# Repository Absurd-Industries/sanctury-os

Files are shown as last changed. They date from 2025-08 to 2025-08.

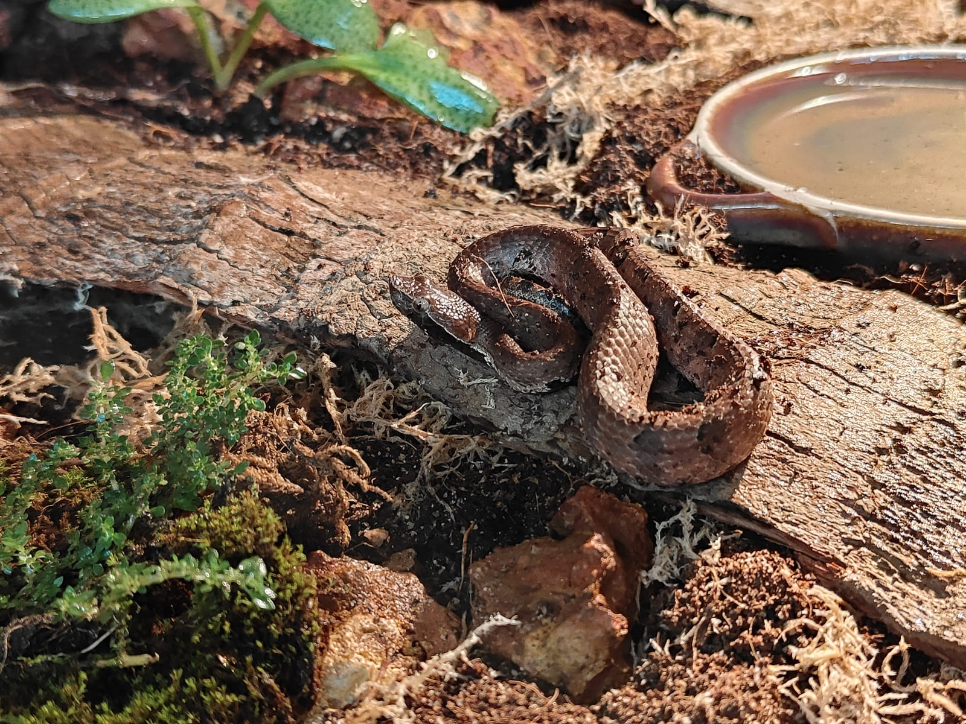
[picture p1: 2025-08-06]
images/HyHyKa01.jpg

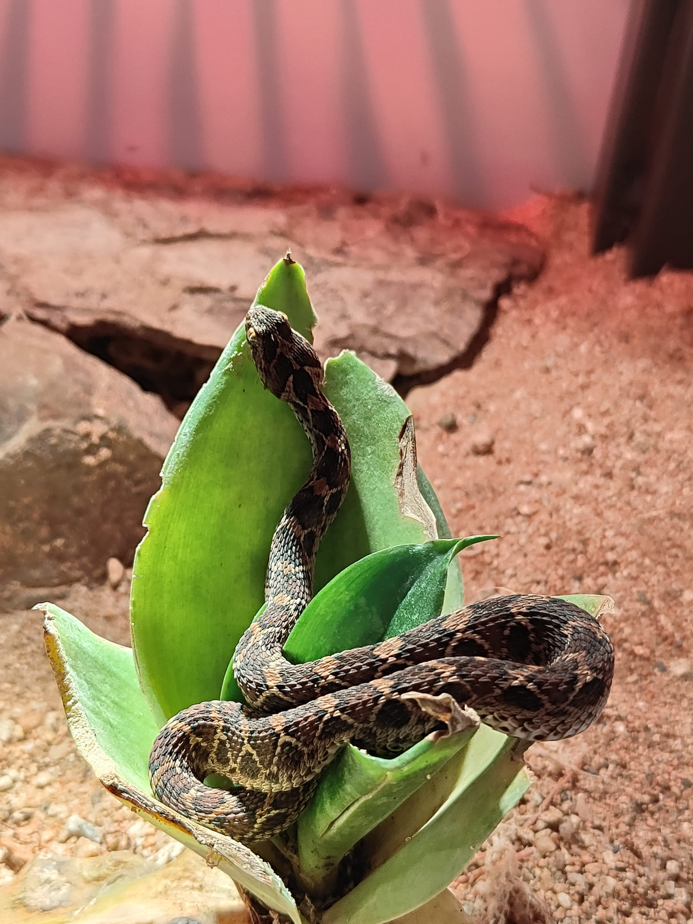
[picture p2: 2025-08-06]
images/EcCaKa01.jpg

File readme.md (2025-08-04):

# Sanctuary OS
## Real-Time Wildlife Conservation Monitoring Platform

  

**Sanctuary OS** is a comprehensive environmental monitoring and management system designed specifically for wildlife conservation facilities. Built by [Absurd Industries](https://absurd.industries) in collaboration with [The Liana Trust](https://www.thelianatrust.org/), UI design by [Code Uncode](https://codeuncode.com) this platform transforms traditional habitat monitoring into an intelligent, real-time conservation tool.

---

## 🐍 **The Problem We're Solving**

Wildlife conservation facilities face critical challenges in maintaining optimal environmental conditions for their residents:

- **Manual monitoring** is time-intensive and prone to human error
- **Environmental fluctuations** can be life-threatening for ectothermic species
- **Data collection** is often fragmented across multiple systems
- **Emergency response** requires immediate awareness of critical changes
- **Research documentation** needs consistent, accurate environmental data

Traditional monitoring methods simply can't provide the granular, real-time data required for modern conservation science.

---

## 🎯 **Our Solution**

Sanctuary OS provides a **unified, intelligent monitoring platform** that combines:

### **Real-Time Environmental Monitoring**
- **Temperature** tracking with ±0.1°C precision
- **Humidity** monitoring with ±2% accuracy  
- **UV Index** measurement for ectothermic health requirements
- **Multi-sensor networks** for comprehensive habitat coverage

### **Intelligent Interface Design**
- **Mobile-first responsive design** for field use
- **Live camera integration** for visual monitoring
- **Glass-morphism overlays** for at-a-glance data visualization
- **Admin-friendly editing** for rapid data updates

### **Conservation-Focused Features**
- **Species-specific optimal ranges** with visual indicators
- **Care schedule tracking** and reminder systems
- **Research note management** for scientific documentation
- **Export capabilities** for academic collaboration

---

## 🔧 **Technical Architecture**

### **Frontend Stack**
- **Vue.js 3** - Reactive framework for dynamic interfaces
- **Tailwind CSS** - Utility-first styling with custom conservation color palette
- **FontAwesome** - Comprehensive iconography
- **Responsive Design** - Mobile-first approach for field accessibility

### **Sensor Integration**
- **Modular sensor networks** supporting 2-10 collection points per enclosure
- **Real-time data streaming** with configurable update frequencies
- **Fail-safe monitoring** with offline data retention
- **Scalable architecture** for facility expansion

### **Data Management**
- **Real-time updates** every 5-60 seconds (configurable)
- **Historical data tracking** for trend analysis
- **CSV export functionality** for research collaboration
- **Backup and redundancy** systems

---

## 📊 **Deployment Configurations**

### **Standard Enclosures**
- **2 sensor collection points** per habitat
- Basic environmental monitoring
- Suitable for: Educational animals, non-critical species

### **Large Enclosures** 
- **10 sensor collection points** per habitat
- Comprehensive environmental mapping
- Suitable for: Venomous species, breeding programs, research subjects

### **Outdoor Habitats**
- **Weather-resistant sensor packages**
- Extended battery life systems
- Solar charging capability
- Suitable for: Semi-natural enclosures, rehabilitation areas

---

## 🛠 **Hardware Requirements (WIP)**

### **Sensor Package (Per Collection Point)**
- **Temperature Sensor**: DHT22 or SHT30 (±0.1°C accuracy)
- **Humidity Sensor**: Integrated with temperature module
- **UV Sensor**: SI1145 or VEML6070 (UV Index measurement)
- **Microcontroller**: ESP32 (WiFi + Bluetooth capability)
- **Power Management**: 5V wired input
- **Enclosure**: IP65-rated weatherproof housing

### **Network Infrastructure**
- **WiFi Access Points** for sensor connectivity
- **Central Hub**: Raspberry Pi 4 or equivalent
- **Backup Storage**: Local SD card + cloud synchronization
- **Display Hardware**: Tablets/monitors for kiosk mode

### **Optional Equipment**
- **Camera Modules**: ESP32-CAM for live feeds
- **Solar Panels**: For outdoor/remote installations
- **LoRa Modules**: For long-range, low-power communication
- **Alarm Systems**: Audio/visual alerts for critical conditions

---

## 📋 **Bill of Materials (BOM) - Placeholder**

*Please provide the following information to generate accurate costings:*

### **Facility Requirements**
- [ ] Total number of enclosures requiring monitoring
- [ ] Number of standard vs. large monitoring setups needed
- [ ] Outdoor enclosure requirements
- [ ] Existing WiFi infrastructure capabilities
- [ ] Power availability at sensor locations

### **Species-Specific Data**
- [ ] Complete list of resident species
- [ ] Optimal temperature ranges for each species
- [ ] Optimal humidity ranges for each species  
- [ ] UV requirements (diurnal vs. nocturnal species)
- [ ] Critical alert thresholds
- [ ] Feeding schedules and care protocols

### **Technical Preferences**
- [ ] Preferred sensor update frequency
- [ ] Data retention requirements
- [ ] Integration with existing systems
- [ ] User access levels and permissions
- [ ] Backup and redundancy preferences

---

## 💡 **Key Benefits**

### **For Conservation**
- **Improved animal welfare** through precise environmental control
- **Enhanced research capabilities** with consistent data collection
- **Reduced monitoring workload** through automation
- **Emergency response** via real-time alerts

### **For Operations**
- **Cost reduction** through efficient resource management
- **Staff productivity** gains from streamlined workflows
- **Visitor education** through transparent monitoring displays
- **Grant applications** strengthened by comprehensive data

### **For Research**
- **High-resolution environmental data** for scientific studies
- **Behavioral correlation** with environmental conditions
- **Breeding program optimization** through precise habitat control
- **Conservation protocol development** based on empirical evidence

---

## 📱 **Live Demo**

Experience Sanctuary OS in action: [**sanctuary.absurd.industries**](https://sanctuary.absurd.industries)

---

## 🤝 **Partnership & Support**

### **Absurd Industries**
Open-source hardware guild committed to building repairable, accessible technology for conservation.

**Contact:** [amit@absurd.industries](mailto:amit@absurd.industries)  
**Web:** [absurd.industries](https://absurd.industries)

---

## 🌱 **Open Source Commitment**

Sanctuary OS is built on open-source principles:

- **Hardware designs** available under Creative Commons
- **Software code** licensed under GPL v3
- **Documentation** freely accessible
- **Community contributions** welcomed and supported

---

*Built with ❤️ by for the global conservation community. Because conservation technology should be accessible to everyone working to protect our planet's biodiversity.*

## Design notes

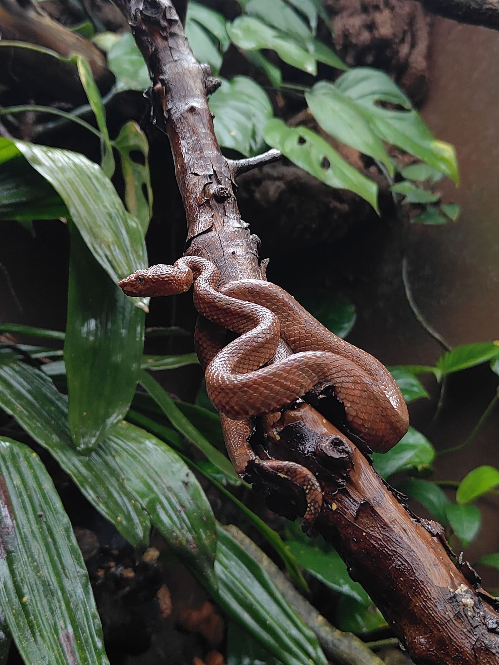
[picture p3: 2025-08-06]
images/CrMlKa03.jpg

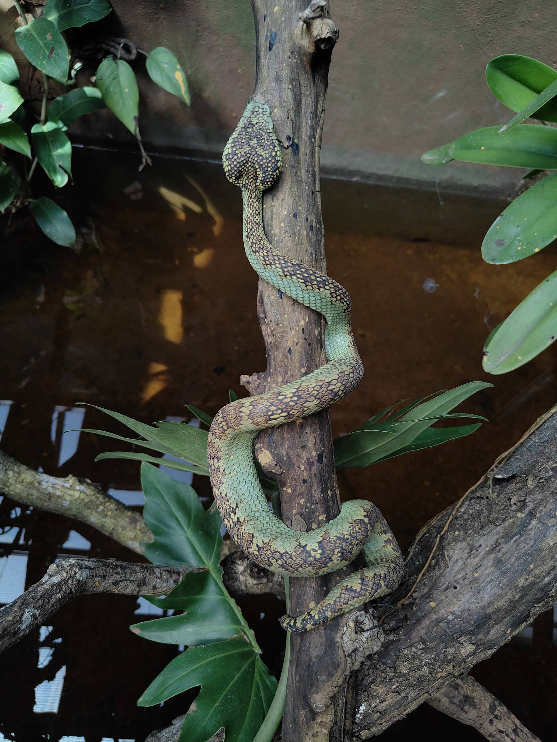
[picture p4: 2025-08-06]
images/CrMlKa02.jpg

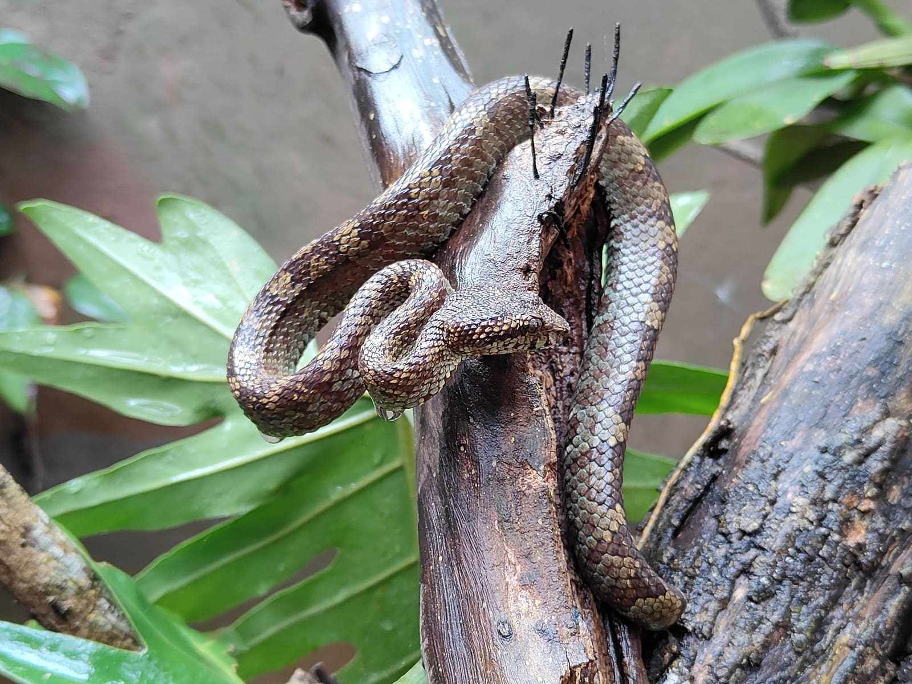
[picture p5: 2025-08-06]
images/CrMlKa01.jpg

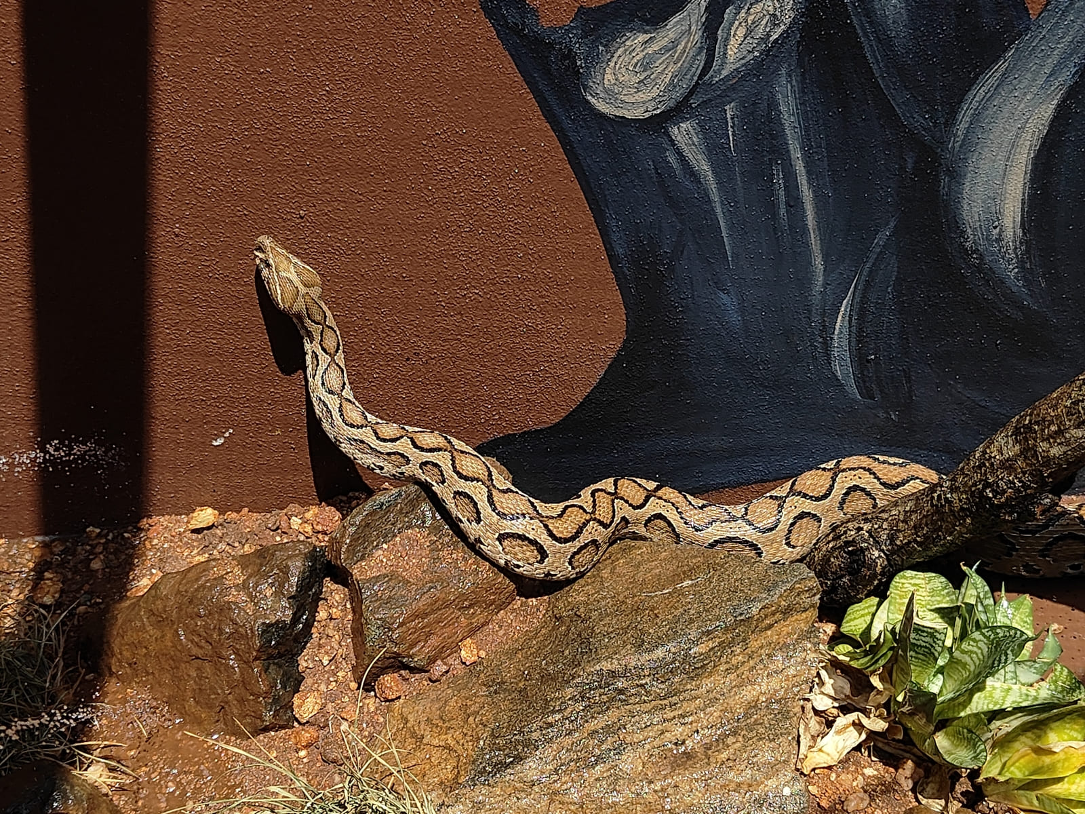
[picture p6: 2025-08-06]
images/DaRuKa05.jpg

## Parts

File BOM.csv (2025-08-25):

Component | Category | Quantity | Unit_Price_INR | Total_Price_INR | Supplier | Supplier_Location | Delivery_Time | Link | Notes
ESP32 Development Board (38-pin) | Core Electronics | 3 | 449 | 1347 | Robocraze | Kalyan Nagar Bengaluru | Same Day | https://robocraze.com/products/esp32-development-board | WiFi + Bluetooth dual-core
BME280 Environmental Sensor | Core Electronics | 3 | 299 | 897 | Robocraze | Kalyan Nagar Bengaluru | Same Day | https://robocraze.com/products/bme280-temperature-sensor-module | ±0.5°C accuracy temp/humidity/pressure
BH1750 Light Sensor | Core Electronics | 3 | 129 | 387 | Robocraze | Kalyan Nagar Bengaluru | Same Day | https://robocraze.com/products/bh1750-light-sensor | 16-bit resolution 1-65535 lux
HC-SR501 PIR Motion Sensor | Core Electronics | 3 | 79 | 237 | Robocraze | Kalyan Nagar Bengaluru | Same Day | https://robocraze.com/products/hcsr501-pir-motion-sensor-passive-infrared-sensor | Passive infrared 3-7m range
ESP32-CAM with OV2640 | Camera System | 3 | 210 | 630 | Robocraze | Kalyan Nagar Bengaluru | Same Day | https://robocraze.com/products/esp32-camera-module | 2MP camera with WiFi streaming
Samsung 18650 2600mAh Battery | Power System | 3 | 317 | 951 | Robu.in | Pan-India | 2-3 Days | https://robu.in/product/samsung-icr18650-26-jm-2600mah-li-ion-battery/ | High-drain lithium-ion cell
TP4056 USB-C Charging Module | Power System | 3 | 169 | 507 | Robu.in | Pan-India | 2-3 Days | https://robu.in/product/tp4056-1a-li-ion-lithium-battery-charging-module-with-current-protection-type-c/ | 1A charging with protection
18650 Battery Holder (SMD) | Power System | 3 | 95 | 285 | Robu.in | Pan-India | 2-3 Days | https://robu.in/product/18650-battery-holder-smd-smt/ | Surface mount design
3.3V Buck/Boost Converter | Power System | 3 | 51 | 153 | Robu.in | Pan-India | 2-3 Days | https://robu.in/product/dc-dc-1-8v-5v-to-3-3v-boost-and-buck-power-module/ | Voltage regulation 1.8V-5V input
JST XH Connectors (Mixed Pack) | Assembly Hardware | 10 | 18 | 180 | Robu.in | Pan-India | 2-3 Days | https://robu.in/product/4-pin-jst-xh-2-54mm-pitch-plug-and-socket-with-cable-5-pcs/ | 2/3/4-pin with cables
Conformal Coating (250ml) | Protection | 1 | 450 | 450 | Robu.in | Pan-India | 2-3 Days | https://robu.in/product/conformal-coating/ | Acrylic PCB protection
Cable Glands & Assembly Parts | Assembly Hardware | 1 | 300 | 300 | Robu.in | Pan-India | 2-3 Days | https://robu.in/ | Mixed components bulk order
IP65 Waterproof Enclosure | Housing | 3 | 400 | 1200 | Amazon India | Bengaluru | 1-2 Days | https://www.amazon.in/s?k=IP65+waterproof+enclosure | 80x120x85mm ABS plastic
PG7 Cable Glands | Housing | 6 | 35 | 210 | GM Modular | Jayanagar Bengaluru | Same Day | https://gmmodular.com/store-locator | Waterproof cable entry
Assembly Materials | Assembly Hardware | 1 | 420 | 420 | Local Suppliers | Bengaluru | Same Day | Various | Wires sealant hardware
10k Resistor Pack | Electronic Components | 1 | 25 | 25 | Robocraze | Kalyan Nagar Bengaluru | Same Day | https://robocraze.com/ | Pull-up resistors for I2C
4.7k Resistor Pack | Electronic Components | 1 | 25 | 25 | Robocraze | Kalyan Nagar Bengaluru | Same Day | https://robocraze.com/ | Standard I2C pull-ups
Status LEDs (Red/Green/Blue) | Electronic Components | 15 | 3 | 45 | Robocraze | Kalyan Nagar Bengaluru | Same Day | https://robocraze.com/ | Power and status indicators
Silicone Wire (22AWG) | Assembly Hardware | 10 | 15 | 150 | Robocraze | Kalyan Nagar Bengaluru | Same Day | https://robocraze.com/ | Flexible high-temp wire
Heat Shrink Tubing Kit | Assembly Hardware | 1 | 80 | 80 | Robocraze | Kalyan Nagar Bengaluru | Same Day | https://robocraze.com/ | Various sizes assortment
Dupont Jumper Wires | Assembly Hardware | 1 | 120 | 120 | Robocraze | Kalyan Nagar Bengaluru | Same Day | https://robocraze.com/ | 120-piece male/female set
M3 Mounting Hardware Kit | Assembly Hardware | 1 | 85 | 85 | Robocraze | Kalyan Nagar Bengaluru | Same Day | https://robocraze.com/ | Screws nuts washers
PCB Standoffs (M3) | Assembly Hardware | 20 | 8 | 160 | Robu.in | Pan-India | 2-3 Days | https://robu.in/ | Component mounting spacers
Aquarium-Safe Silicone Sealant | Protection | 2 | 120 | 240 | Local Hardware Store | Bengaluru | Same Day | Local | Non-toxic weatherproofing
Acrylic Sheet (Clear 2mm) | Housing | 1 | 200 | 200 | Local Plastics Supplier | Bengaluru | Same Day | Local | Light sensor windows
Antenna Extension Cable (SMA) | Connectivity | 3 | 45 | 135 | Robu.in | Pan-India | 2-3 Days | https://robu.in/ | External WiFi antenna option

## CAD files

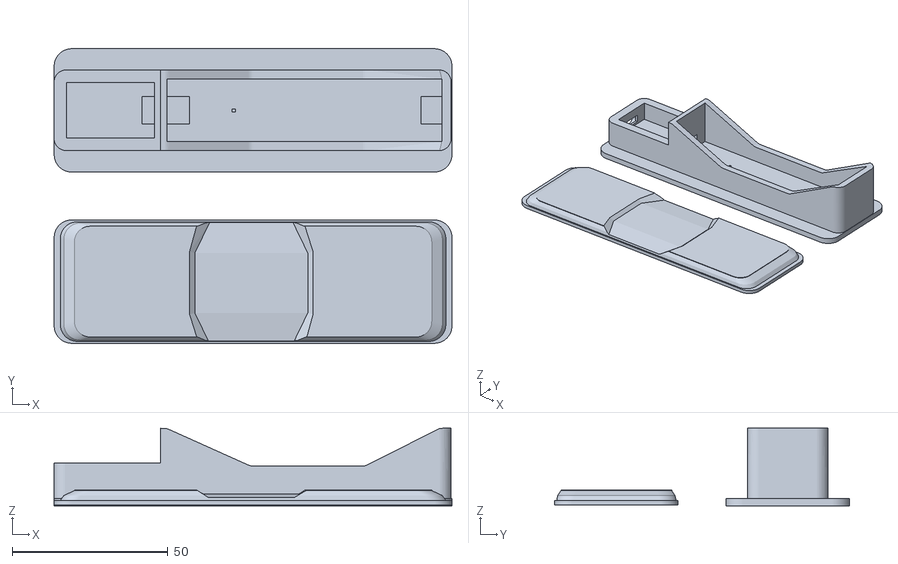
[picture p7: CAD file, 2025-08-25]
3d-models/INSIDE BOTH LAYERS.stl
127.9 x 94.7 x 24.9

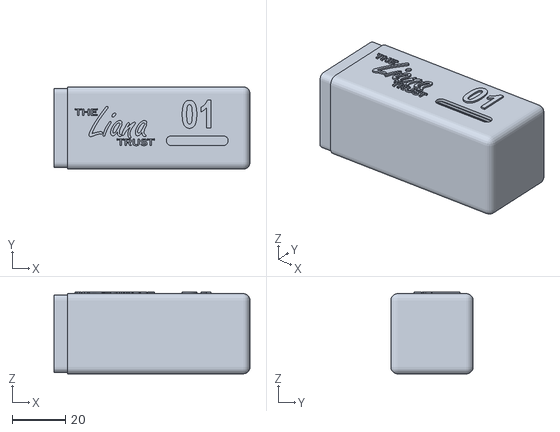
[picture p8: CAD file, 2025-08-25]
3d-models/print/CASE BODY.stl
73.8 x 30.9 x 30.8

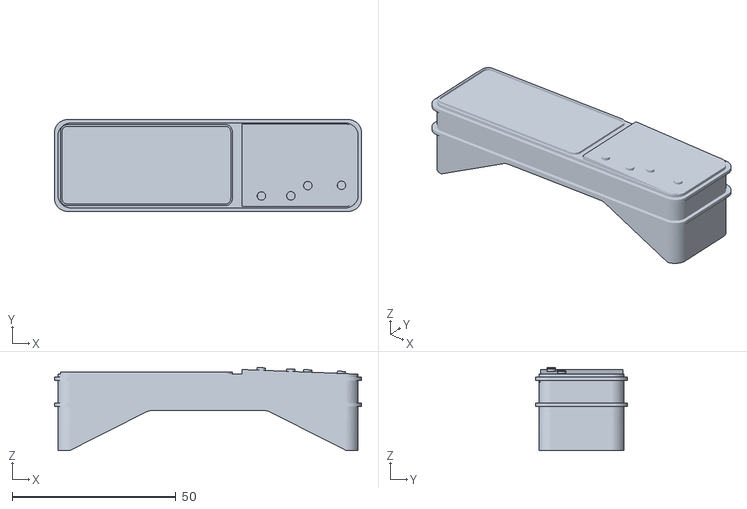
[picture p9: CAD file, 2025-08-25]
3d-models/iner pod v2.stl
93.7 x 28.1 x 25.4

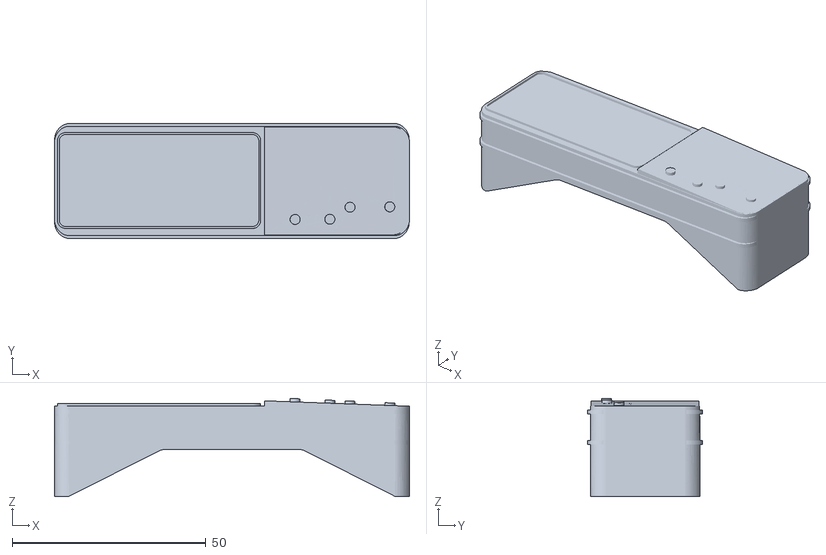
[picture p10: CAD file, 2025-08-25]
3d-models/print/sensor-pod-body.stl
91.6 x 29.7 x 25.4

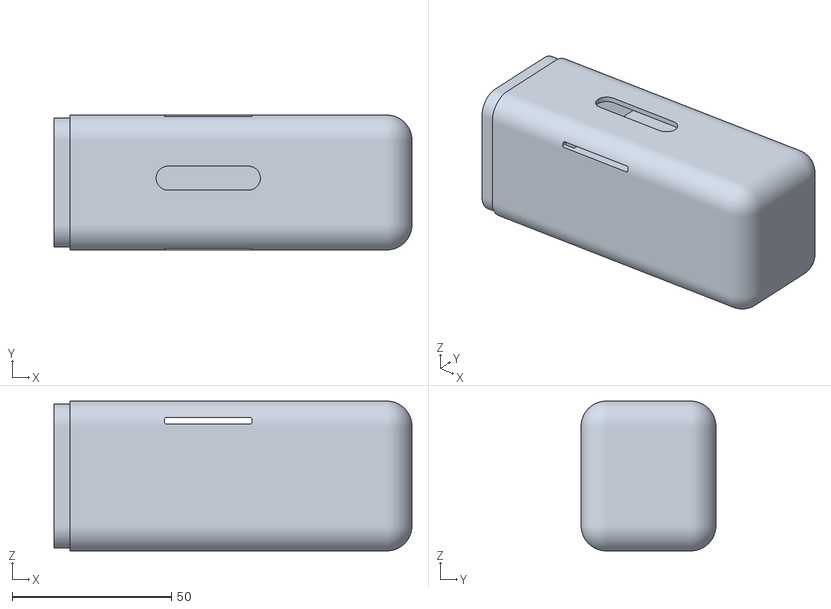
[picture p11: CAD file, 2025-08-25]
3d-models/case.stl
112.3 x 42.3 x 47.0

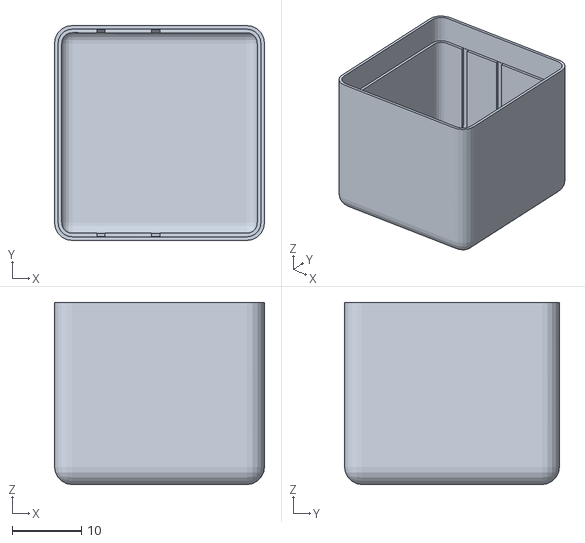
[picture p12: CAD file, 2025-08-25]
3d-models/print/CASE LID.stl
30.2 x 30.9 x 26.2

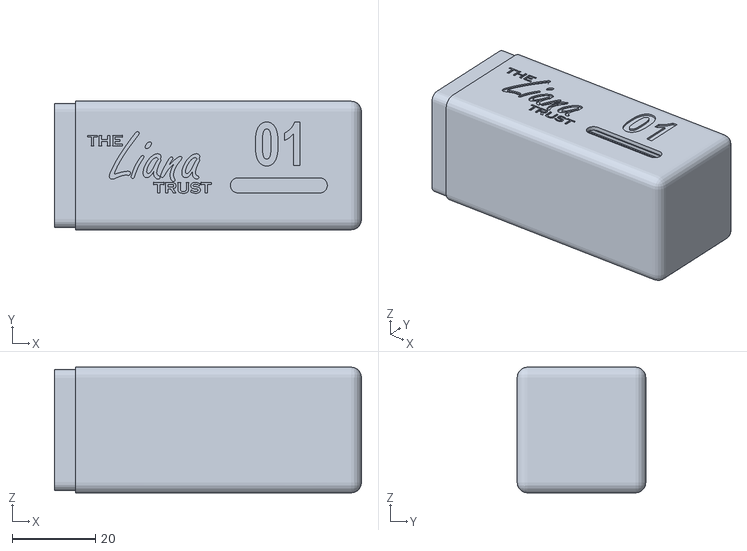
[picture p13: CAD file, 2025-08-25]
3d-models/print/BODY CASE WITH LOGO.stl
73.8 x 30.9 x 30.2

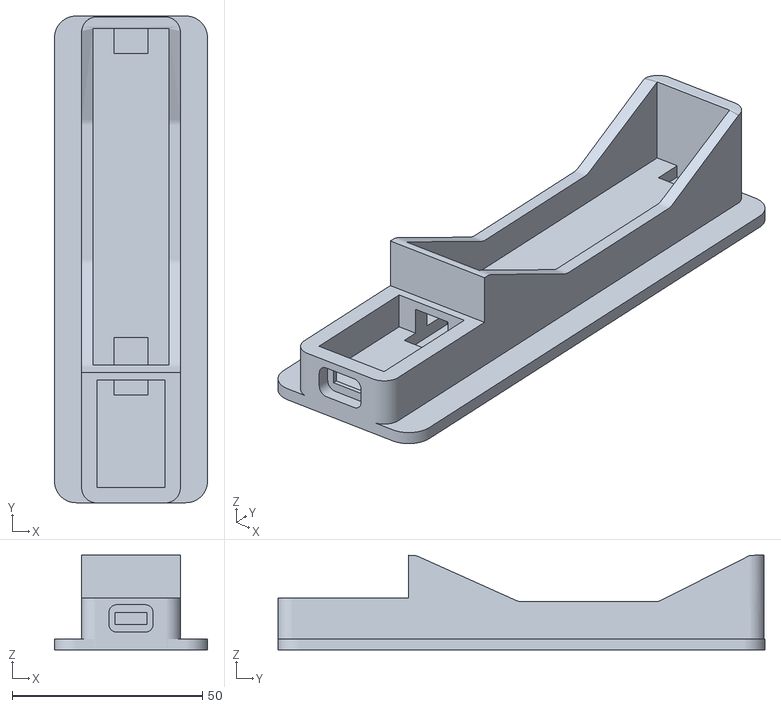
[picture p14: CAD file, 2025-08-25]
3d-models/18650-tp4056-holder-test.stl
40.2 x 127.9 x 24.8

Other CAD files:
3d-models/sensor-pod-body.blend
3d-models/sensor-pod-body.obj

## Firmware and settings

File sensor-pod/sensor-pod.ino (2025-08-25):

/**
 * Wildlife Conservation Monitoring System - The Liana Trust
 * "Actually Works This Time" Edition 🐍
 * 
 * Hardware: PCB Cupid Glyph C3 (ESP32-C3)
 * Sensors: BH1750 Light Sensor, BME280 Environmental Sensor
 * Purpose: Snake habitat monitoring that Lisa will absolutely LOVE
 * 
 * Authors: Amartha (Maximum Sass Division) & Amit (The Snake Whisperer)
 * Version: 2.0.0 - "Complete and Fabulous Edition"
 * Date: When snakes learn to code (approximately now)
 */

// ===== LIBRARY IMPORTS =====
#include <WiFi.h>
#include <PubSubClient.h>
#include <ArduinoJson.h>
#include <Wire.h>
#include <BH1750.h>
#include <BME280I2C.h>  // Tyler Green's library - because it actually works
#include "esp_task_wdt.h"
#include "esp_sleep.h"
#include <time.h>
#include <ESPmDNS.h>

// ===== HARDWARE CONFIGURATION =====
// I2C Pin Configuration for PCB Cupid Glyph C3
#define I2C_SDA 4          // GPIO4 - I2C Data Line
#define I2C_SCL 5          // GPIO5 - I2C Clock Line
#define CS_PIN 0           // GPIO0 - Chip Select on D0
#define LED_PIN 2          // Built-in LED for status indication

// Sensor I2C Addresses
#define BH1750_ADDR 0x23   // Light sensor address (ADD pin LOW/floating)
#define BME280_ADDR 0x76   // Environmental sensor default address

// ===== NETWORK CONFIGURATION =====
const char* WIFI_SSID = "@manjusstudio";
const char* WIFI_PASSWORD = "wifi2020!";

// MQTT Configuration with intelligent fallback system
const char* MQTT_BROKER_HOSTNAME = "liana.local";       // Primary target
const char* MQTT_BROKER_IP = "192.168.1.100";          // UPDATE THIS IP!
const char* MQTT_TEST_BROKER = "test.mosquitto.org";   // Public test broker
const int MQTT_PORT = 1883;
const char* MQTT_CLIENT_ID = "sanctuary_glyph_c3_001";
const char* MQTT_USER = "";      // Add if your broker requires auth
const char* MQTT_PASSWORD = "";  // Add if your broker requires auth

// MQTT Topics - Wildlife Conservation Standard
const char* TOPIC_SENSOR_DATA = "liana/habitat/sensors";
const char* TOPIC_ALERTS = "liana/habitat/alerts";
const char* TOPIC_STATUS = "liana/habitat/status";
const char* TOPIC_COMMANDS = "liana/habitat/commands";
const char* TOPIC_DIAGNOSTICS = "liana/habitat/diagnostics";

// ===== TIMING CONFIGURATION (in seconds) =====
const unsigned long SENSOR_READ_INTERVAL = 30;      // Read sensors every 30 seconds
const unsigned long MQTT_PUBLISH_INTERVAL = 60;     // Publish every minute for demo
const unsigned long WIFI_CHECK_INTERVAL = 30;       // Check WiFi every 30 seconds
const unsigned long HEARTBEAT_INTERVAL = 300;       // Heartbeat every 5 minutes
const uint32_t WDT_TIMEOUT = 30;                     // Watchdog timeout

// ===== WILDLIFE MONITORING THRESHOLDS =====
// Temperature thresholds for snake habitats (Celsius)
const float TEMP_CRITICAL_LOW = 15.0;    // Critical low temperature
const float TEMP_CRITICAL_HIGH = 40.0;   // Critical high temperature
const float TEMP_WARNING_LOW = 18.0;     // Warning low temperature
const float TEMP_WARNING_HIGH = 35.0;    // Warning high temperature
const float TEMP_OPTIMAL_MIN = 22.0;     // Optimal range minimum
const float TEMP_OPTIMAL_MAX = 30.0;     // Optimal range maximum

// Humidity thresholds (%)
const float HUMIDITY_CRITICAL_LOW = 20.0;
const float HUMIDITY_CRITICAL_HIGH = 95.0;
const float HUMIDITY_WARNING_LOW = 30.0;
const float HUMIDITY_WARNING_HIGH = 85.0;
const float HUMIDITY_OPTIMAL_MIN = 45.0;
const float HUMIDITY_OPTIMAL_MAX = 75.0;

// Light thresholds (lux) for day/night cycle detection
const float LUX_DAY_THRESHOLD = 100.0;
const float LUX_NIGHT_THRESHOLD = 10.0;
const float LUX_TWILIGHT_THRESHOLD = 50.0;

// ===== GLOBAL OBJECTS =====
BH1750 lightMeter;
BME280I2C bme;    // Tyler Green's BME280 library - the hero we deserved
WiFiClient wifiClient;
PubSubClient mqttClient(wifiClient);

// Connection state tracking
String currentMqttBroker = "";
int currentMqttPort = 0;
bool usingTestBroker = false;

// ===== DATA STRUCTURES =====
struct SensorReading {
  unsigned long timestamp;
  float temperature;
  float humidity;
  float pressure;
  float light_lux;
  int wifi_rssi;
  String light_condition;  // "day", "night", "twilight"
  bool temp_critical;
  bool temp_warning;
  bool humidity_critical;
  bool humidity_warning;
  bool all_optimal;
};

struct AlertLevel {
  String severity;  // "critical", "warning", "info"
  String type;      // "temperature", "humidity", "light", "system"
  String message;
  unsigned long timestamp;
};

// Data buffer for offline storage (because network outages happen)
#define BUFFER_SIZE 100
SensorReading dataBuffer[BUFFER_SIZE];
int bufferIndex = 0;
int bufferCount = 0;

// Alert tracking
AlertLevel lastAlert;
bool alertActive = false;
unsigned long lastAlertTime = 0;

// ===== TIMING VARIABLES =====
unsigned long lastSensorRead = 0;
unsigned long lastMqttPublish = 0;
unsigned long lastWifiCheck = 0;
unsigned long lastHeartbeat = 0;
unsigned long bootTime = 0;
unsigned long totalUptime = 0;
int reconnectAttempts = 0;
int totalMqttPublishes = 0;
int totalAlerts = 0;

// ===== STATUS FLAGS =====
bool sensorsInitialized = false;
bool bmeWorking = false;
bool lightSensorWorking = false;
bool wifiConnected = false;
bool mqttConnected = false;
bool systemHealthy = true;

// ===== FUNCTION DECLARATIONS =====
void initializeSensors();
void connectWiFi();
void connectMQTT();
void reconnectMQTT();
void checkConnections();
SensorReading readSensors();
void publishSensorData(SensorReading& reading);
void publishAlert(AlertLevel alert);
void checkEnvironmentalAlerts(SensorReading& reading);
void storeReading(SensorReading& reading);
void publishBufferedData();
void publishHeartbeat();
void mqttCallback(char* topic, byte* payload, unsigned int length);
void handleCommand(String command, String value);
bool isI2CDevicePresent(uint8_t address);
void printDiagnostics();
void blinkLED(int times, int delayMs = 200);
String getSystemStatus();
String getLightCondition(float lux);
void enterDeepSleep(uint64_t seconds);

// ===== SETUP FUNCTION =====
void setup() {
  // Initialize serial communication for debugging
  Serial.begin(115200);
  delay(1000);
  
  Serial.println("\n" + String("="));
  Serial.println("WILDLIFE CONSERVATION MONITORING SYSTEM");
  Serial.println("Device: PCB Cupid Glyph C3 (ESP32-C3)");
  Serial.println("Purpose: The Liana Trust Snake Habitat Monitoring");
  Serial.println(String("=") + "\n");
  
  // Initialize hardware pins
  pinMode(CS_PIN, OUTPUT);
  digitalWrite(CS_PIN, HIGH);  // Deselect by default
  pinMode(LED_PIN, OUTPUT);
  
  // Boot indication - because feedback is important
  blinkLED(3, 100);
  
  // Initialize watchdog timer for ESP32-C3 (because things can go wrong)
  esp_task_wdt_config_t wdt_config = {
    .timeout_ms = WDT_TIMEOUT * 1000,
    .idle_core_mask = (1 << portNUM_PROCESSORS) - 1,
    .trigger_panic = true
  };
  esp_task_wdt_init(&wdt_config);
  esp_task_wdt_add(NULL);
  Serial.println("✓ Watchdog timer initialized (30s timeout)");
  
  // Initialize I2C bus with proper error handling
  Wire.begin(I2C_SDA, I2C_SCL);
  Wire.setClock(100000);  // 100kHz for maximum reliability
  Serial.println("✓ I2C bus initialized on SDA=GPIO4, SCL=GPIO5");
  
  // Comprehensive I2C device scan
  Serial.println("\n🔍 Scanning I2C bus for devices...");
  bool devicesFound = false;
  for (byte address = 1; address < 127; address++) {
    Wire.beginTransmission(address);
    if (Wire.endTransmission() == 0) {
      Serial.print("  📍 I2C device found at 0x");
      if (address < 16) Serial.print("0");
      Serial.print(address, HEX);
      
      // Identify known devices
      switch(address) {
        case 0x23: Serial.println(" (BH1750 Light Sensor)"); break;
        case 0x76: Serial.println(" (BME280 Environmental Sensor)"); break;
        case 0x77: Serial.println(" (BME280 Alt Address)"); break;
        default: Serial.println(" (Unknown Device)"); break;
      }
      devicesFound = true;
    }
  }
  
  if (!devicesFound) {
    Serial.println("  ⚠️  No I2C devices found! Check your wiring!");
  }
  
  // Initialize sensors with comprehensive error handling
  initializeSensors();
  
  // Connect to WiFi network
  connectWiFi();
  
  // Configure MQTT client
  mqttClient.setCallback(mqttCallback);
  mqttClient.setBufferSize(1024);  // Larger buffer for complex payloads
  mqttClient.setKeepAlive(60);     // 60 second keep-alive
  
  // Connect to MQTT broker with fallback logic
  connectMQTT();
  
  // Record boot time for uptime calculations
  bootTime = millis();
  
  // Take initial sensor reading and publish system status
  if (lightSensorWorking || bmeWorking) {
    SensorReading initial = readSensors();
    
    Serial.println("\n📊 Initial sensor readings:");
    if (bmeWorking) {
      Serial.printf("  🌡️  Temperature: %.2f°C\n", initial.temperature);
      Serial.printf("  💧 Humidity: %.2f%%\n", initial.humidity);
      Serial.printf("  🏔️  Pressure: %.2f hPa\n", initial.pressure);
    }
    if (lightSensorWorking) {
      Serial.printf("  ☀️  Light: %.2f lux (%s)\n", initial.light_lux, initial.light_condition.c_str());
    }
    
    // Store initial reading
    storeReading(initial);
    
    // Publish initial status if MQTT is connected
    if (mqttConnected) {
      publishSensorData(initial);
      publishHeartbeat();
    }
  }
  
  Serial.println("\n✅ System initialization complete!");
  Serial.println("🚀 Starting main monitoring loop...\n");
  
  // Success indication
  blinkLED(5, 100);
}

// ===== MAIN MONITORING LOOP =====
void loop() {
  // Reset watchdog timer to prevent system reset
  esp_task_wdt_reset();
  
  // Handle MQTT communication
  if (mqttConnected) {
    mqttClient.loop();
  }
  
  // Periodic connection health checks
  if (millis() - lastWifiCheck >= WIFI_CHECK_INTERVAL * 1000) {
    checkConnections();
    lastWifiCheck = millis();
  }
  
  // Read sensors at specified interval
  if (millis() - lastSensorRead >= SENSOR_READ_INTERVAL * 1000) {
    if (lightSensorWorking || bmeWorking) {
      SensorReading reading = readSensors();
      
      // Check for environmental alerts
      checkEnvironmentalAlerts(reading);
      
      // Store reading in circular buffer
      storeReading(reading);
      
      // Print diagnostics to serial
      printDiagnostics();
      
      lastSensorRead = millis();
    }
  }
  
  // Publish MQTT data at specified interval
  if (millis() - lastMqttPublish >= MQTT_PUBLISH_INTERVAL * 1000) {
    if (mqttConnected && bufferCount > 0) {
      // Publish latest reading
      int latestIndex = (bufferIndex - 1 + BUFFER_SIZE) % BUFFER_SIZE;
      publishSensorData(dataBuffer[latestIndex]);
      
      // Publish buffered data if we have accumulated readings
      if (bufferCount > 1) {
        publishBufferedData();
      }
      
      totalMqttPublishes++;
      lastMqttPublish = millis();
    }
  }
  
  // Send periodic heartbeat
  if (millis() - lastHeartbeat >= HEARTBEAT_INTERVAL * 1000) {
    if (mqttConnected) {
      publishHeartbeat();
    }
    lastHeartbeat = millis();
  }
  
  // Small delay to prevent CPU hogging
  delay(50);
}

// ===== COMPREHENSIVE SENSOR INITIALIZATION =====
void initializeSensors() {
  Serial.println("\n🔧 Initializing sensors...");
  
  // Initialize BH1750 light sensor
  Serial.print("  📈 BH1750 Light Sensor: ");
  if (isI2CDevicePresent(BH1750_ADDR)) {
    if (lightMeter.begin(BH1750::CONTINUOUS_HIGH_RES_MODE)) {
      lightSensorWorking = true;
      Serial.println("✅ WORKING");
      
      // Test read to verify functionality
      float testLux = lightMeter.readLightLevel();
      if (testLux >= 0) {
        Serial.printf("    Initial reading: %.2f lux\n", testLux);
      }
    } else {
      Serial.println("❌ INITIALIZATION FAILED");
    }
  } else {
    Serial.println("❌ NOT DETECTED (Check address 0x23)");
  }
  
  // Initialize BME280 environmental sensor using Tyler Green's library
  Serial.print("  🌡️  BME280 Environmental Sensor: ");
  
  // Try multiple I2C addresses for BME280
  uint8_t bmeAddresses[] = {0x76, 0x77};
  bool bmeInitialized = false;
  
  for (int i = 0; i < 2 && !bmeInitialized; i++) {
    if (isI2CDevicePresent(bmeAddresses[i])) {
      Serial.print("(0x");
      Serial.print(bmeAddresses[i], HEX);
      Serial.print(") ");

      bme.begin();
      
      // Initialize with Tyler Green's library
      // Test sensor by reading values
      float temp(NAN), hum(NAN), pres(NAN);
      bme.read(pres, temp, hum, BME280::TempUnit_Celsius, BME280::PresUnit_hPa);
      
      // Validate readings are reasonable
      if (!isnan(temp) && temp > -50 && temp < 100 && 
          !isnan(hum) && hum >= 0 && hum <= 100 &&
          !isnan(pres) && pres > 800 && pres < 1200) {
        
        bmeWorking = true;
        bmeInitialized = true;
        Serial.println("✅ WORKING");
        Serial.printf("    Initial readings: %.1f°C, %.1f%%, %.1f hPa\n", 
                      temp, hum, pres);
      }
    }
  }
  
  if (!bmeWorking) {
    Serial.println("❌ FAILED");
    Serial.println("    Check: VCC→3.3V, GND→GND, SDA→GPIO4, SCL→GPIO5");
    Serial.println("    Verify: 4.7kΩ pull-up resistors on SDA/SCL lines");
  }
  
  // Set overall sensor status
  sensorsInitialized = (lightSensorWorking || bmeWorking);
  
  if (sensorsInitialized) {
    Serial.println("✅ Sensor initialization completed successfully!");
  } else {
    Serial.println("❌ Sensor initialization failed!");
    Serial.println("⚠️  System will continue but functionality will be limited");
  }
}

// ===== ROBUST WiFi CONNECTION =====
void connectWiFi() {
  Serial.print("\n📶 Connecting to WiFi network: ");
  Serial.println(WIFI_SSID);
  
  WiFi.mode(WIFI_STA);
  WiFi.begin(WIFI_SSID, WIFI_PASSWORD);
  
  int attempts = 0;
  while (WiFi.status() != WL_CONNECTED && attempts < 30) {
    delay(500);
    Serial.print(".");
    attempts++;
    esp_task_wdt_reset();  // Reset watchdog during connection
  }
  
  if (WiFi.status() == WL_CONNECTED) {
    wifiConnected = true;
    Serial.println("\n✅ WiFi connected successfully!");
    Serial.printf("  📍 IP Address: %s\n", WiFi.localIP().toString().c_str());
    Serial.printf("  📶 Signal strength: %d dBm (%s)\n", 
                  WiFi.RSSI(), 
                  WiFi.RSSI() > -50 ? "Excellent" : 
                  WiFi.RSSI() > -60 ? "Good" : 
                  WiFi.RSSI() > -70 ? "Fair" : "Poor");
    
    // Configure NTP for accurate timestamps
    configTime(0, 0, "pool.ntp.org", "time.nist.gov");
    Serial.println("  🕐 NTP time synchronization configured");
    
    // Initialize mDNS for .local domain resolution
    if (MDNS.begin("sanctuary-monitor")) {
      Serial.println("  🌐 mDNS responder started");
    }
    
  } else {
    wifiConnected = false;
    Serial.println("\n❌ WiFi connection failed!");
    Serial.println("    Check: SSID, password, and network availability");
  }
}

// ===== INTELLIGENT MQTT CONNECTION WITH FALLBACK =====
void connectMQTT() {
  if (!wifiConnected) {
    Serial.println("❌ Cannot connect to MQTT - WiFi not connected");
    return;
  }
  
  Serial.println("\n📡 Attempting MQTT broker connections...");
  
  // Define multiple connection targets for maximum reliability
  struct MQTTServer {
    const char* name;
    const char* address;
    int port;
    bool isTest;
    const char* description;
  };
  
  MQTTServer servers[] = {
    {"Liana Local", MQTT_BROKER_HOSTNAME, MQTT_PORT, false, "Primary conservation facility broker"},
    {"Fallback IP", MQTT_BROKER_IP, MQTT_PORT, false, "Direct IP connection"},
    {"Test Broker", MQTT_TEST_BROKER, MQTT_PORT, true, "Public test broker (development only)"}
  };
  
  // Try each server in sequence
  for (int serverIndex = 0; serverIndex < 3; serverIndex++) {
    MQTTServer& server = servers[serverIndex];
    
    Serial.printf("\n📡 Trying %s (%s:%d)\n", server.name, server.address, server.port);
    Serial.printf("    %s\n", server.description);
    
    if (server.isTest) {
      Serial.println("    ⚠️  WARNING: This is a PUBLIC test broker!");
    }
    
    mqttClient.setServer(server.address, server.port);
    
    int attempts = 0;
    while (!mqttClient.connected() && attempts < 3) {
      String clientId = String(MQTT_CLIENT_ID) + "_" + String(random(0xffff), HEX);
      
      Serial.printf("    Attempt %d/3: ", attempts + 1);
      
      if (mqttClient.connect(clientId.c_str(), MQTT_USER, MQTT_PASSWORD)) {
        mqttConnected = true;
        currentMqttBroker = server.address;
        currentMqttPort = server.port;
        usingTestBroker = server.isTest;
        
        Serial.println("✅ SUCCESS!");
        
        if (server.isTest) {
          Serial.println("    🚨 REMOVE TEST BROKER IN PRODUCTION! 🚨");
        }
        
        // Subscribe to command topic for remote management
        if (mqttClient.subscribe(TOPIC_COMMANDS)) {
          Serial.printf("    📬 Subscribed to: %s\n", TOPIC_COMMANDS);
        }
        
        // Publish initial connection status
        StaticJsonDocument<400> doc;
        doc["device_id"] = MQTT_CLIENT_ID;
        doc["status"] = "online";
        doc["ip"] = WiFi.localIP().toString();
        doc["rssi"] = WiFi.RSSI();
        doc["broker"] = server.name;
        doc["broker_address"] = server.address;
        doc["test_mode"] = server.isTest;
        doc["sensors_available"] = sensorsInitialized;
        doc["bme280_working"] = bmeWorking;
        doc["bh1750_working"] = lightSensorWorking;
        doc["firmware_version"] = "2.0.0";
        doc["boot_time"] = bootTime;
        
        char buffer[400];
        serializeJson(doc, buffer);
        mqttClient.publish(TOPIC_STATUS, buffer, true);  // Retained message
        
        return; // Success! Exit function
        
      } else {
        Serial.printf("❌ FAILED (rc=%d) ", mqttClient.state());
        
        // Decode MQTT error codes for better diagnostics
        switch(mqttClient.state()) {
          case -4: Serial.println("[Connection timeout]"); break;
          case -3: Serial.println("[Connection lost]"); break;
          case -2: Serial.println("[Connect failed - broker unreachable]"); break;
          case -1: Serial.println("[Disconnected]"); break;
          case 1: Serial.println("[Bad protocol version]"); break;
          case 2: Serial.println("[Bad client ID]"); break;
          case 3: Serial.println("[Broker unavailable]"); break;
          case 4: Serial.println("[Bad credentials]"); break;
          case 5: Serial.println("[Unauthorized]"); break;
          default: Serial.println("[Unknown error]"); break;
        }
        
        attempts++;
        if (attempts < 3) {
          delay(2000);
        }
      }
      esp_task_wdt_reset();
    }
  }
  
  // If we reach here, all connection attempts failed
  mqttConnected = false;
  Serial.println("\n❌ All MQTT connection attempts failed!");
  Serial.println("\n🔧 Troubleshooting checklist:");
  Serial.println("   1. Verify MQTT broker is running on liana.local");
  Serial.println("   2. Test: ping liana.local");
  Serial.println("   3. Update MQTT_BROKER_IP constant with correct IP");
  Serial.println("   4. Check firewall settings (port 1883)");
  Serial.println("   5. Verify broker accepts anonymous connections");
  Serial.println("   6. Check network connectivity");
}

// ===== CONNECTION HEALTH MONITORING =====
void checkConnections() {
  // Check WiFi connection health
  if (WiFi.status() != WL_CONNECTED) {
    if (wifiConnected) {
      Serial.println("⚠️  WiFi connection lost - attempting reconnection");
      wifiConnected = false;
    }
    
    WiFi.reconnect();
    delay(3000);
    
    if (WiFi.status() == WL_CONNECTED) {
      wifiConnected = true;
      Serial.println("✅ WiFi reconnected successfully");
    }
  } else {
    wifiConnected = true;
  }
  
  // Check MQTT connection health
  if (wifiConnected && !mqttClient.connected()) {
    if (mqttConnected) {
      Serial.println("⚠️  MQTT connection lost - attempting reconnection");
      mqttConnected = false;
    }
    reconnectMQTT();
  }
}

// ===== MQTT RECONNECTION LOGIC =====
void reconnectMQTT() {
  if (!wifiConnected) return;
  
  static unsigned long lastReconnectAttempt = 0;
  unsigned long now = millis();
  
  // Attempt reconnection every 10 seconds
  if (now - lastReconnectAttempt > 10000) {
    lastReconnectAttempt = now;
    
    String clientId = String(MQTT_CLIENT_ID) + "_" + String(random(0xffff), HEX);
    
    if (mqttClient.connect(clientId.c_str(), MQTT_USER, MQTT_PASSWORD)) {
      mqttConnected = true;
      Serial.println("✅ MQTT reconnected successfully");
      
      // Resubscribe to command topic
      mqttClient.subscribe(TOPIC_COMMANDS);
      
      // Publish reconnection status
      publishHeartbeat();
      
      // Publish any buffered data
      if (bufferCount > 0) {
        Serial.println("📤 Publishing buffered data after reconnection");
        publishBufferedData();
      }
      
      reconnectAttempts = 0;
      
    } else {
      reconnectAttempts++;
      Serial.printf("❌ MQTT reconnection failed (attempt %d)\n", reconnectAttempts);
      
      // If too many failures, try a complete WiFi restart
      if (reconnectAttempts > 5) {
        Serial.println("🔄 Too many MQTT failures - restarting WiFi connection");
        WiFi.disconnect();
        delay(2000);
        connectWiFi();
        if (wifiConnected) {
          connectMQTT();
        }
        reconnectAttempts = 0;
      }
    }
  }
}
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

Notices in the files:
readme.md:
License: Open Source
